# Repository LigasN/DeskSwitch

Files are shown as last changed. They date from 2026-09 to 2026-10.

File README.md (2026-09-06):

# Desk Power Controller & Enclosure

A compact, 3D-printed mounting solution designed for efficient power management at your desk. This project features a custom enclosure for a power switch and a current limiter, keeping your workspace organized, safe, and clutter-free.

## Features
* **Custom Enclosure:** Sleek, low-profile housing for your power switch and current limiter.
* **Desk-Mounted:** Secure, ergonomic design for easy access without taking up valuable workspace.
* **Cable Management:** Optimized for clean routing to keep cables hidden and tidy.
* **3D Print Ready:** Clean, manifold topology (quad-based) for reliable, high-quality printing.

## Technical Details
* **Software:** Designed in Blender (100% Quad-based topology for structural integrity).
* **Components:** 
    * **Cam Switch:** LW26 cam switch
    * **Inrush Current Limiter:** Mean Well ICL-16
* **Setup:** Ready for mounting under your desk.

## License
This project is provided for personal, non-commercial use only. You may modify and share the files for personal projects, but you may not sell the prints or the digital files for profit unless under my personal approval. 

---
*Built for a cleaner, smarter workspace.*

---

## Externals:
### LW26 visualisation model
LW26 YMW26-25 rotary cam changeover switch mockup by AS_Motion_Lab on Thingiverse: https://www.thingiverse.com/thing:3611525

#### Under license: 
This thing was created by Thingiverse user AS_Motion_Lab, and is licensed under Creative Commons - Attribution

#### Readme: 
```txt
LW26 YMW26-25 rotary cam changeover switch mockup by AS_Motion_Lab on Thingiverse: https://www.thingiverse.com/thing:3611525

Summary:
This is a dimensionally accurate mockup of the ubiquitous rotary cam switch, for your mocking up pleasure.Like this one:https://www.aliexpress.com/item/LW28-20-LW26-20-YMW26-series-Electric-2-3-4-Position-8-Terminals-Rotary-Cam-Changeover/32862171520.htmlHandy if you're building control panels and need dimensions.Step, STL and Fusion 360 files attached.PS it's semi-exploded just to show you the separate components. They can be moved down in Y to fit your panel thickness.If it saves you some time, send me some beer tokens :)
```

#### Modifications And Use:
Scalling, positioning, materials, separating parts. Used in the blend project for visualisation.

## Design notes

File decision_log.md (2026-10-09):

# Desk Switch Enclosure Dimensions

## Wall Widths
* Base Plate: 3.6 mm
* Front Wall: 2.6 mm
* Side Walls: 2.6 mm
* Back Wall: 2.6 mm

## Base Plate Slide Track
* Height: 1.8 mm
* Depth: 3.4 mm

## Side Wall Slider
* Height: 1.6 mm
* Depth: 3.2 mm

## Gaps
* For the cables connected to the switch: 9 mm
* Gap from the walls to the switch mounting: 1 mm

## Seating step (Slider and Slide Track)
* Height: 0.2 mm (equal to margin between slider and slide track)
* Length: 3 mm

## Under-Desk Mounting
* Screw Type: Pan head wood screws
* Quantity: 4 (corners)
### Measured Screw Specs
* Thread Diameter: 3.8 mm
* Root Diameter: 2.5 mm
* Head Diameter: 7.5 mm
* Head Height: 2.8 mm
* Neck Expansion: 4.0 mm (height: 1.5 mm)
* Screw Length: 15.5 mm
### Base Plate Clearance Holes
* Hole Diameter: 4.5 mm
* Head Seating Surface: Flat
* Min Wall Width Around Hole: 1.2 mm
* Min Clearance to Screw Head Edge: 0.5 mm
### Desk Pilot Holes & Engagement
* Pilot Hole Diameter: 2.5 mm
* Pilot Hole Depth: 12.0 mm

## Mounting Standoffs
* Height: 5 mm
* Width: 11 mm
* Depth: 11 mm
### Corner Brackets
* Width: 1 mm
* Height: 2 mm
### Pilot Holes
* Diameter: 1.8 mm (screw root diameter: 1.9 mm, screw thread diameter: 2.9 mm)
* Depth: 4.5 mm (screw thread length: 9.6 mm, meanwell clearance hole depth: 3.4 mm, screw depth: 6.2 mm)
* Perimeters: 4-5

## Enclosure Boss
### Screw
* Length: 9.1 mm
* Head length: 1.5 mm
* Thread length: 7.6 mm
* Thread diameter: 2.44 mm
* Root diameter: 1.9 mm
* Head diameter: 4.24 mm

### Screw Boss
* Height: 4.4 mm (part of the screw will go through the base plate, with its width it gives 8 mm)
* Width: 8 mm (edit: +1 mm to the opposite side to cable clamp to make it harder to break)
* Depth: 10 mm (required length = pilot hole depth + margin)

### Screw Hole
* Opening in the enclosure diameter: 2.6 mm
* Head counterbore diameter: 4.4 mm
* Head counterbore length: 1.6 mm
  
### Pilot Hole
* Diameter: 2.2 mm
* Depth: 7.6 mm (screw root length - (wall width - head counterbore length) + margin (1 mm))
* Perimeters: 4-5

## Faceplate
* Wall thickness: 1 mm
* Flange depth (sides & bottom): Core body wall thickness (2.6 mm)
* Flange width: 2.8 mm
* Top Flange: Designed as a pair of alignment ribs extending along the flange depth behind the front wall.
* Perimeters: 4–5
* Orientation: Printed flat on the print bed for a pristine surface finish.

## Ventilation & Cooling Grids (Dual-Color Hex Grid)

### Print Specification (0.2 mm Nozzle)
| Parameter | Value | Notes / Calculation |
| :--- | :--- | :--- |
| **Nozzle Profile** | `0.2 mm` | Line width: `0.20 mm` – `0.22 mm` |
| **Total Panel Thickness** | `2.6 mm` | Aligned with main enclosure wall thickness |
| **Main Hexagon (Frame - Color A)** | `Ø 10.0 mm` | Outer hexagon diameter |
| **Frame A Rib Thickness** | `1.8 mm` | Exactly 9 full wall lines for 0.2 mm nozzle (updated) |
| **Micro-mesh (Infill - Color B)**  | `Ø 1.2 mm`  | Hexagonal mesh cell size |
| **Micro-mesh Rib Thickness B** | `0.6 mm` | Exactly 3 full wall lines for 0.2 mm nozzle |
| **Material Overlap (MMU/AMS)** | `0.6 mm` | Exactly 3 wall lines per side; ensures robust mechanical interlock (updated) |

### Z-Axis Layout (2.6 mm Wall Cross-Section)
* **0.0 mm – 0.6 mm (Exterior):** Front protective lip (Frame A) – Recessed micro-mesh for aesthetics and mechanical protection.
* **0.6 mm – 1.8 mm (Core):** Main micro-mesh structure (Color B) with a height of `1.2 mm`.
* **1.8 mm – 2.6 mm (Interior):** Rear stiffening lip (Frame A) at `0.8 mm` thick, reinforcing the enclosure structure from inside.

### Technical Rationale & Decisions
* **100% Solid Wall Alignment:** The `0.6 mm` micro-rib width and `1.8 mm` frame thickness divide cleanly into 3 and 9 perimeter paths for a `0.2 mm` nozzle, resulting in 100% solid wall density with continuous extrusion loops.
* **Passive Convection:** The ratio of cell size (`1.2 mm`) to rib thickness (`0.6 mm`) maintains high airflow permeability for passive cooling while ensuring high structural rigidity.
* **Robust Mechanical Interlock:** Utilizing a `0.6 mm` material overlap provides a solid 3-wall connection per side, completely eliminating fractional toolpaths and securely locking the micro-mesh into the main frame while maintaining structural continuity in Z.

## Cable clamp
* Minimal wall width: 2 mm
* Minimal height of the top guide rail: 1.6 mm
* Cable radious: 4 mm - 7 mm
* Base wall min width: 3 mm

### Screw M2:
* Thread length: 20 mm
* Thread diameter: 2 mm
* Opening diameter: 2.2 mm

#### Head
* Diameter: 3.7 mm
* Height: 1.9 mm

#### Nut
* Width across corners: 4.5 mm
* Thickness: 1.5 mm

#### Flat Washer
* Outer Diameter: 4.9 mm
* Thickness: 0.2 mm

### Cable Clamp Retention Rib

* **Feature:** Internal circular retention rib (strain relief) inside the cable clamp channel.
* **Height:** 0.4 mm (optimized to bite securely into the external rubber/PVC cable jacket without risking damage to internal live wire insulation).
* **Base Width:** 0.8 mm

## LW26 Mounting
I have decided not to use the dimensions from the LW26 model (https://www.thingiverse.com/thing:3611525/files) as it is not exactly the same as the one I bought. However, it still remains in the project as a visual model of the future part.

### Main Shaft / Central Opening
* Diameter: 16.0 mm (clearance for the main rotary shaft/axis of the LW26 switch)

### Knob
* Width: 5 mm
* Cylinder: 15 mm
* Opening: 16 mm

### Screw
* Thread diameter: max 3.88 mm
* Clearance Opening: 5.0 mm (0.5 mm tolerance/clearance; rotation locking and positioning handled entirely by alignment ribs, screws serve clamping function only)
* Opening edge distance to the center of knob opening: 17.92 mm

### Anti-Rotation Alignment Blocks
* **Design Type:** Point-contact wall ribs (replacing continuous walls) to allow easy manual post-processing and filing if necessary.
* **Placement:** Two ribs per wall, positioned at approximately 1/3 and 2/3 of each wall's length (total of 8 ribs across 4 walls).
* **Rib Width:** 1.6 mm
* **Rib Length (Span along wall):** 8.0 mm
* **Height:** 4.0 mm

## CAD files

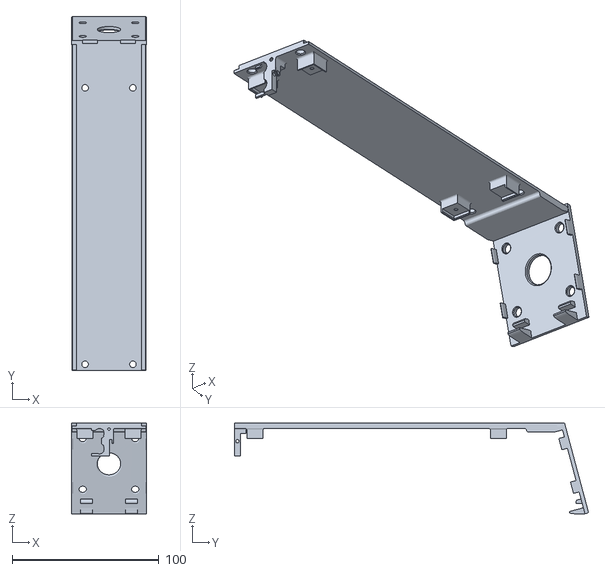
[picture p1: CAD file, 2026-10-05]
prints/mount.stl
50.9 x 241.5 x 61.8

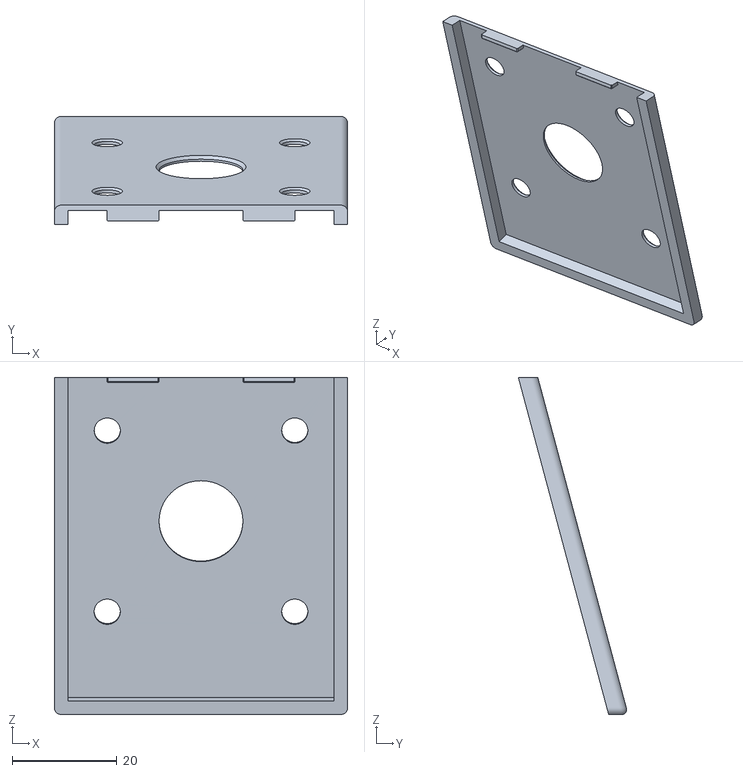
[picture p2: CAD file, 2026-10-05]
prints/faceplate.stl
56.1 x 20.7 x 64.4

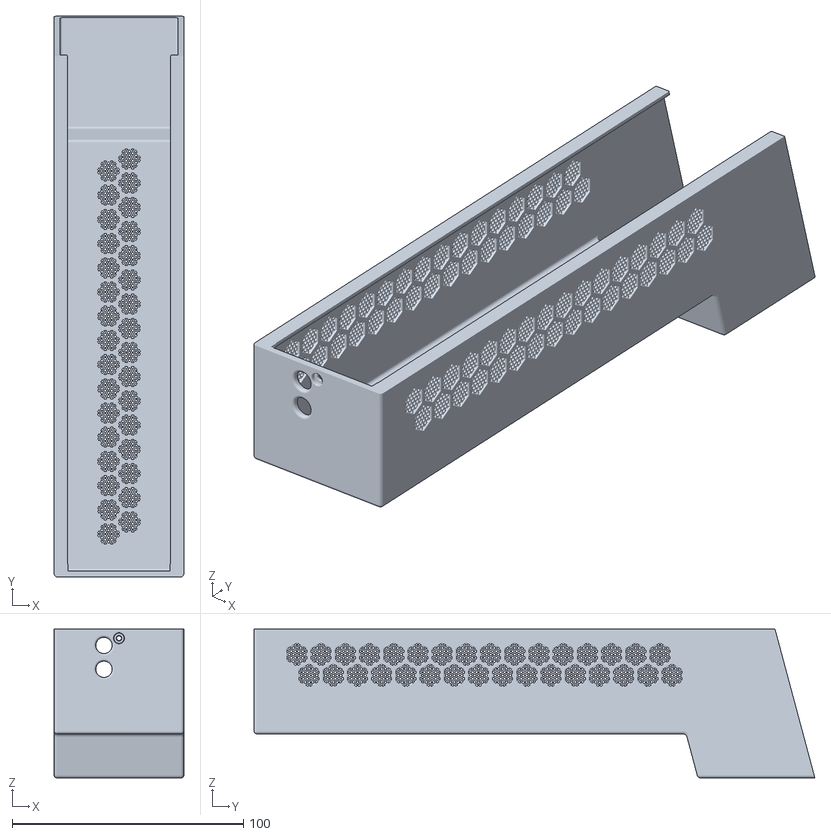
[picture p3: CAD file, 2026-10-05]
prints/enclosure.stl
56.1 x 242.4 x 64.4

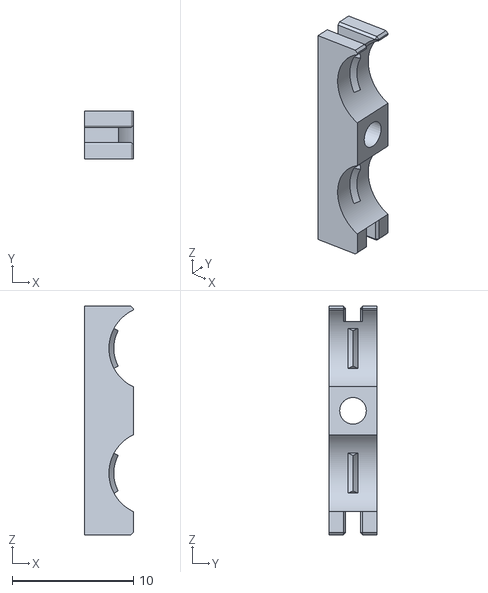
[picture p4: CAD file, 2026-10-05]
prints/cable_clamp.stl
4.00 x 4.00 x 18.9

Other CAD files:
DeskSwitch.blend

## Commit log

2026-07-15 Revise README for Desk Power Controller project
    Updated project description and added features, technical details, and license information.
2026-07-15 blender project + gitignore
    [DeskSwitch.blend]
2026-07-15 blender project update
    [DeskSwitch.blend]
2026-07-25 switch snapped to mount face
    [DeskSwitch.blend]
2026-07-25 switch sposition set
    [DeskSwitch.blend]
2026-07-25 switch all transforms applied
    [DeskSwitch.blend]
2026-07-25 mount all transforms applied
    [DeskSwitch.blend]
2026-07-26 side walls, front wall sides, switch finish setup
    [DeskSwitch.blend]
2026-07-28 back for the enclosure, meanwell cube
    [DeskSwitch.blend]
2026-07-31 bottom for enclosure
    [DeskSwitch.blend]
2026-08-01 mount groove
    [DeskSwitch.blend]
2026-08-01 mounting tongue
    [DeskSwitch.blend]
2026-08-01 Seating steps
    [DeskSwitch.blend]
2026-08-04 Seating steps part 2
    [DeskSwitch.blend]
2026-08-04 meanwell cable opening
    [DeskSwitch.blend]
2026-08-04 Mounting standoffs
    [DeskSwitch.blend]
2026-08-05 Enclosure boss
    [DeskSwitch.blend]
2026-08-06 Enclosure boss - screw opening
    [DeskSwitch.blend]
2026-08-08 pilot holes
    [DeskSwitch.blend]
2026-08-10 cable pass-through cutout
    [DeskSwitch.blend]
2026-08-23 planned mounting screws
2026-08-24 screws found for under desk mount
2026-08-25 planned mounting screws in the 3D model
    [DeskSwitch.blend]
2026-08-26 fixed enclosure
    [DeskSwitch.blend]
2026-08-27 vents - single hex modelling started
    [DeskSwitch.blend]
2026-08-29 vents - micro mesh
    [DeskSwitch.blend]
2026-08-30 material - tryout with 3d print realistic material - to be removed
    [DeskSwitch.blend]
2026-08-31 vents - A rib decision 1.8mm
    [DeskSwitch.blend]
2026-09-01 vents - sides
    [DeskSwitch.blend]
2026-09-01 vents - bottom
    [DeskSwitch.blend]
2026-09-01 vents - micromeshes joined
    [DeskSwitch.blend]
2026-09-01 vents - frames cut in the enclosure
    [DeskSwitch.blend]
2026-09-02 vents - topology fixed
    [DeskSwitch.blend]
2026-09-02 cables - blockade v.1
    [DeskSwitch.blend]
2026-09-03 cables - clamp
    [DeskSwitch.blend]
2026-09-04 cables - screws
    [DeskSwitch.blend]
2026-09-05 cables - nut holder, face fixes
    [DeskSwitch.blend]
2026-09-05 knob - main opening
    [DeskSwitch.blend]
2026-09-06 knob - antirotation aligment blocks
    [DeskSwitch.blend]
2026-09-06 cables - openings in the enclosure
    [DeskSwitch.blend]
2026-09-06 lw26 materials
    [DeskSwitch.blend]
2026-09-07 remove edges used for measurement
    [DeskSwitch.blend]
2026-09-07 cable clamp - bevels and retention rib
    [DeskSwitch.blend]
2026-09-17 bevel - mount + cable clamp retention rib on mount part
    [DeskSwitch.blend]
2026-09-18 bevel - enclosing part1
    [DeskSwitch.blend]
2026-09-27 bevel - enclosing part2
    [DeskSwitch.blend]
2026-09-27 bevel - enclosing part3 vents
    [DeskSwitch.blend]
2026-09-27 bevel - front face
    [DeskSwitch.blend]
2026-09-29 bevel - lw26 aligment
    [DeskSwitch.blend]
2026-09-29 front face thickened transition
    [DeskSwitch.blend]
2026-10-01 faceplate - separated
    [DeskSwitch.blend]
2026-10-01 fix mount screw holes positions
    [DeskSwitch.blend]
2026-10-02 front face and mount screw openings positioned and scaled for 0.5mm tolerance
    [DeskSwitch.blend]
2026-10-03 front face finished
    [DeskSwitch.blend]
2026-10-09 fixes v.1
    [DeskSwitch.blend]
2026-10-10 front face aligment pins
    [DeskSwitch.blend]
2026-10-10 vertex fix
    [DeskSwitch.blend]
2026-10-15 mount v.2
2026-10-15 mount stl
